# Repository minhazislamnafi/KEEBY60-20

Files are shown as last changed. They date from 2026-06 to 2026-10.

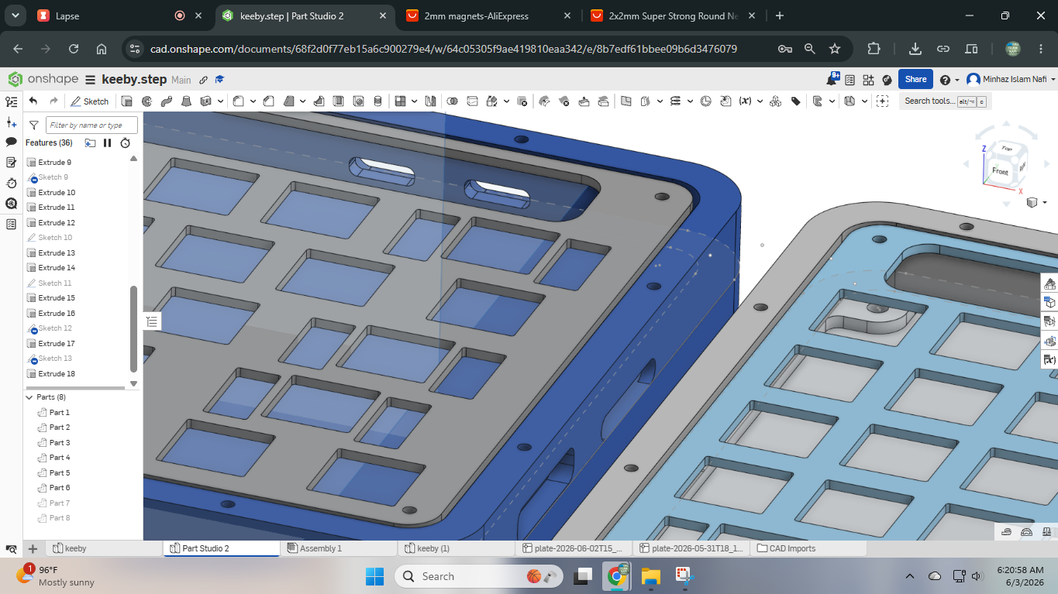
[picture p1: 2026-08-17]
DOCS/Screenshot 2026-06-03 062100.png

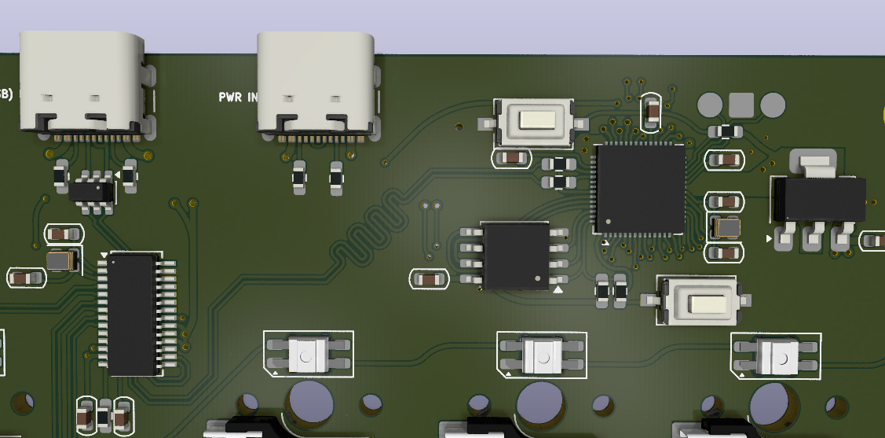
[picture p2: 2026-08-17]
DOCS/Screenshot 2026-06-07 144513.png

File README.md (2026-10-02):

# KEEBY60+20

A moduler 60% mechanical hot-swapble keyboard. With 20% numpad attachment, it will form a proper 80% keyboard.






GITHUB REPO

# Specification

## KEEBY60
* Firmware: QMK
* Layout: Default 60% (main Keyboard)
* Socket: Hot-swapable Kailh Socket
* Switches: Cherry MX blue
* ARGB led: SK6812 mini-E
* MCU: Raspberry Pi RP2040 QFN-56
* USB hub IC: Fe1.1s SSOP-28
* USB IN: 2 type-C (One for USB+Power & another for only power)
* USB OUT: 1 6p magnetic connector & 2 type-c usb 2.0
        
     (2 USB 2.0 is only accessible when only 60% is used)
* Total keys: 63 ANSI layout
* Knob: EC11E rotary encoder (with push switch)
* Diaplay: SSD1306 0.91" I2C Oled 
* PCB: 2-layer (all components bottom mounted)
* Dimensions: pcb - 291* 116 mm (L * W)                                                                        
              case - 304* 130*45 mm  (L * W * H)

## KEEBY20
* firmware: QMK
* Layout: ISO 20% (numpad)
* Socket: Hot-swapable Kailh Socket
* Switches: Cherry MX blue
* ARGB led: SK6812 mini-E
* MCU: Raspberry Pi RP2040 QFN-56
* USB IN: 6p magnetic connector & 1 type-C

     (Both the 6p conn and type-C connector's data pin are connected)
* Total keys: 17 ANSI Numpad
* Knob: EC11E rotary encoder (with push switch)
* Diaplay: SSD1306 0.91" I2C Oled 
* PCB: 2-layer (all components bottom mounted)
* Dimensions: pcb - 81* 116 mm (L * W)                                                                         
              case - 95* 130*45 mm (L * W * H)

# Ask Why KEEBY60+20?

It's a freaking 80% moduler usb2.0 hub, mechanical hot-swappable programmable ARGB LED DIY 3D printed Keyboard with dual knob dual OLED display. wants to know more? It can be used as a single 60% ANSI with 2 USB 2.0 HUB or, a single 17-key numpad macropad or or or as said, a 6-pin magnetic-connected ISO 80% Keyboard. 

TL;DR - The KEEBY60+20 is an all-around very versatile keyboard that runs on open-source QMK firmware.

## Onshape Full assembly [Link](https://cad.onshape.com/documents/68f2d0f77eb15a6c900279e4/w/64c05305f9ae419810eaa342/e/0ee3c387e4a094a987680ffc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)

## CAD Render
CAD render

## Schematics
Keeby60v2_page-0001

Keeby60v2_page-0003

## PCB Render
My PC can't handle KiCad 10.0 now. so no render ;(
But I have some screenshots.









## FOLLOW THESE STEPS FOR BUILDING ##

**1. Spend some money $$ to buy the parts mentioned in [BOM](https://github.com/minhazislamnafi/KEEBY60-20/tree/main/PCB/production).**(2 separate BOM)

**2. Order the PCB for KEEBY60 and KEEBY20 using this [GERBER file](https://github.com/minhazislamnafi/KEEBY60-20/blob/main/PCB/production/keeby60/KEEBY_60_v1.1.zip) and [GERBER file](https://github.com/minhazislamnafi/KEEBY60-20/blob/main/PCB/production/keeby20/KEEBY_20_v1.1.zip).**

**3. Solder the SMD components of the PCB by hand ;) Or just order the PCBs with PCBA services, btw it will cost a lot.**

**4. Check with a multimeter: Is the MCU getting 3.3v or not? If not, diagnose by yourself :)**

**5. Place all the key switches.**

**6. Flash QMK firmware using USB connection ( I will add every step in details, once I have built IRL:)**

**7. 3D print the [Case](https://github.com/minhazislamnafi/KEEBY60-20/tree/main/CAD/CASE%203D%20file) .**

**8. Assemble your KEEBY60 and 20.**

**5. Test and enjoy more RGB= more FPS keyboard ( I will add every step in details, once I have built IRL:).**

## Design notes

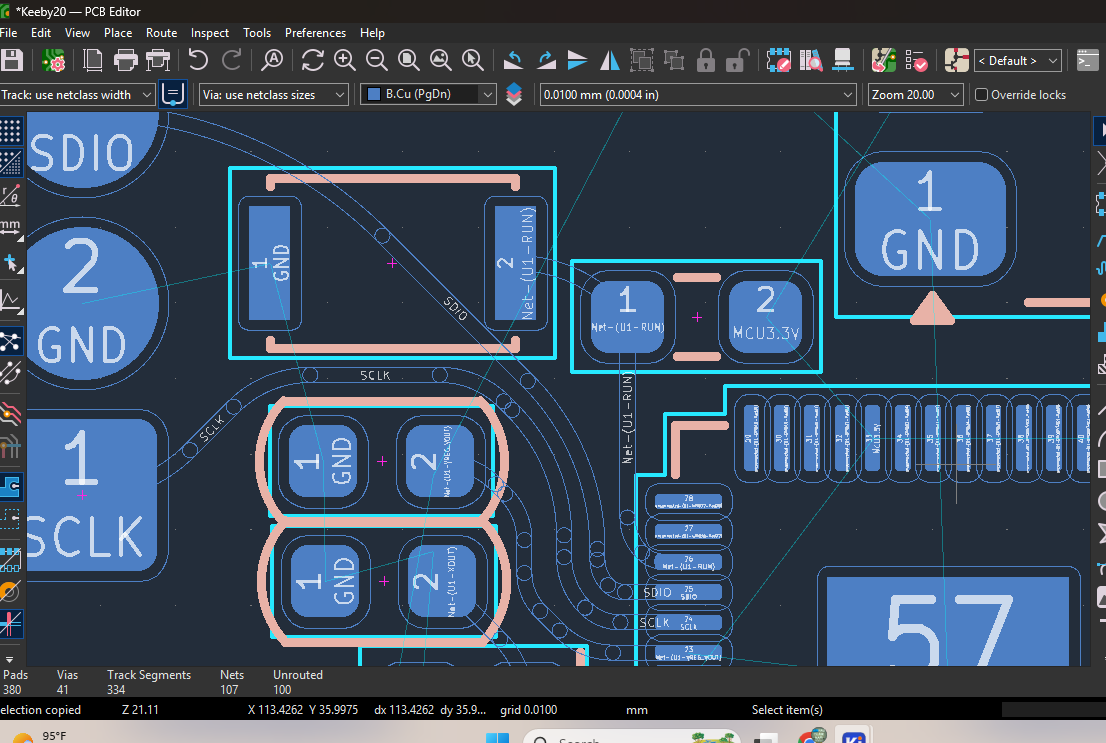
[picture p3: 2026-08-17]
DOCS/Screenshot 2026-05-31 063714.png

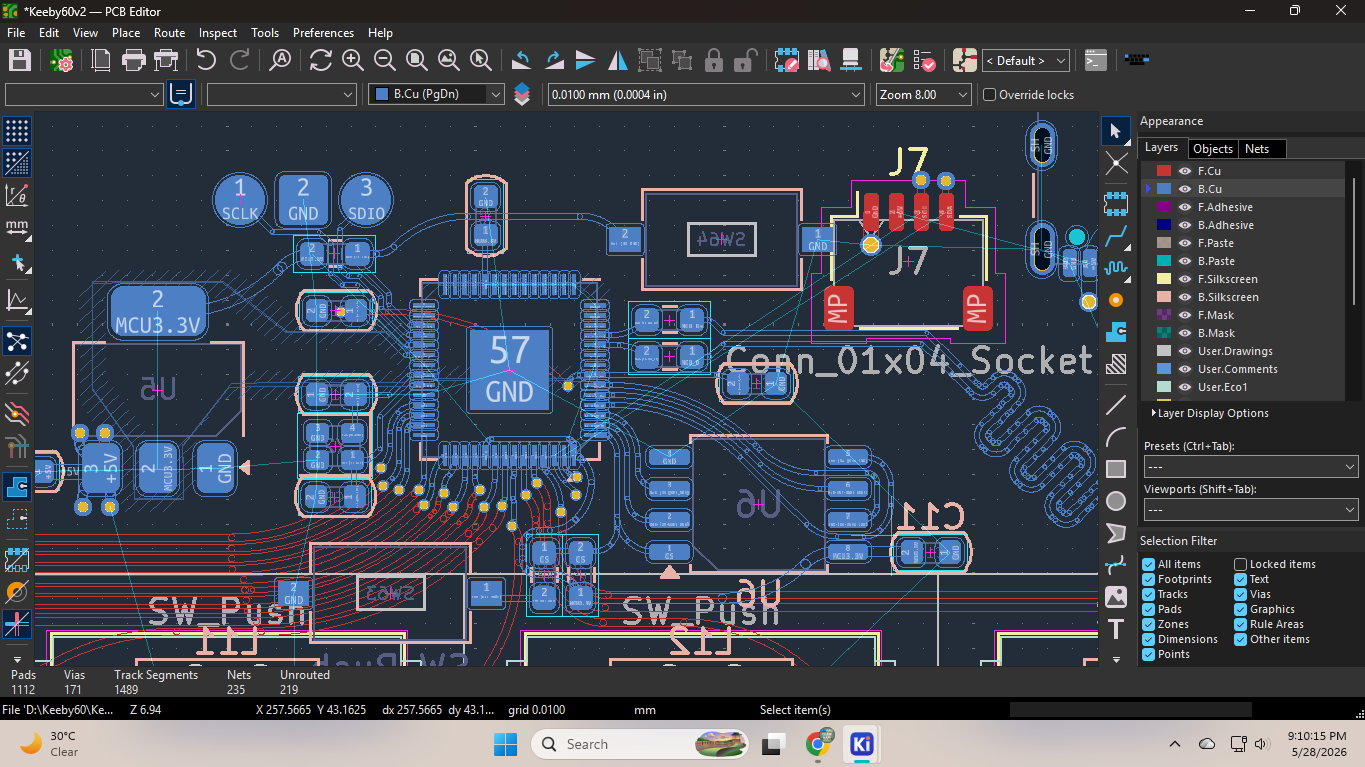
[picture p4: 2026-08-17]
DOCS/Screenshot 2026-05-28 211016.png

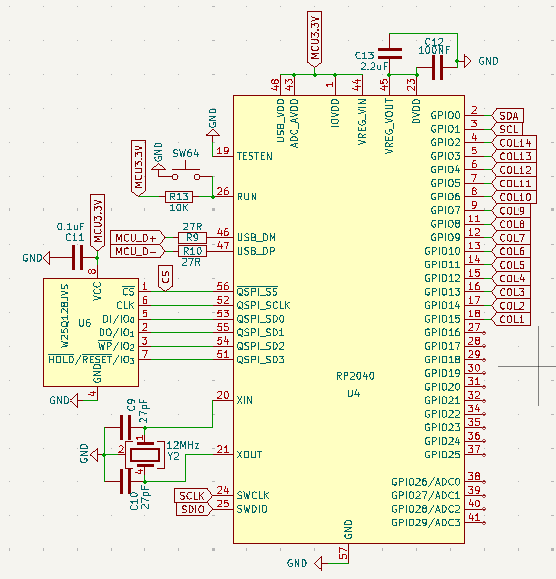
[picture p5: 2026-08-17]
DOCS/Screenshot 2026-05-28 212009.png

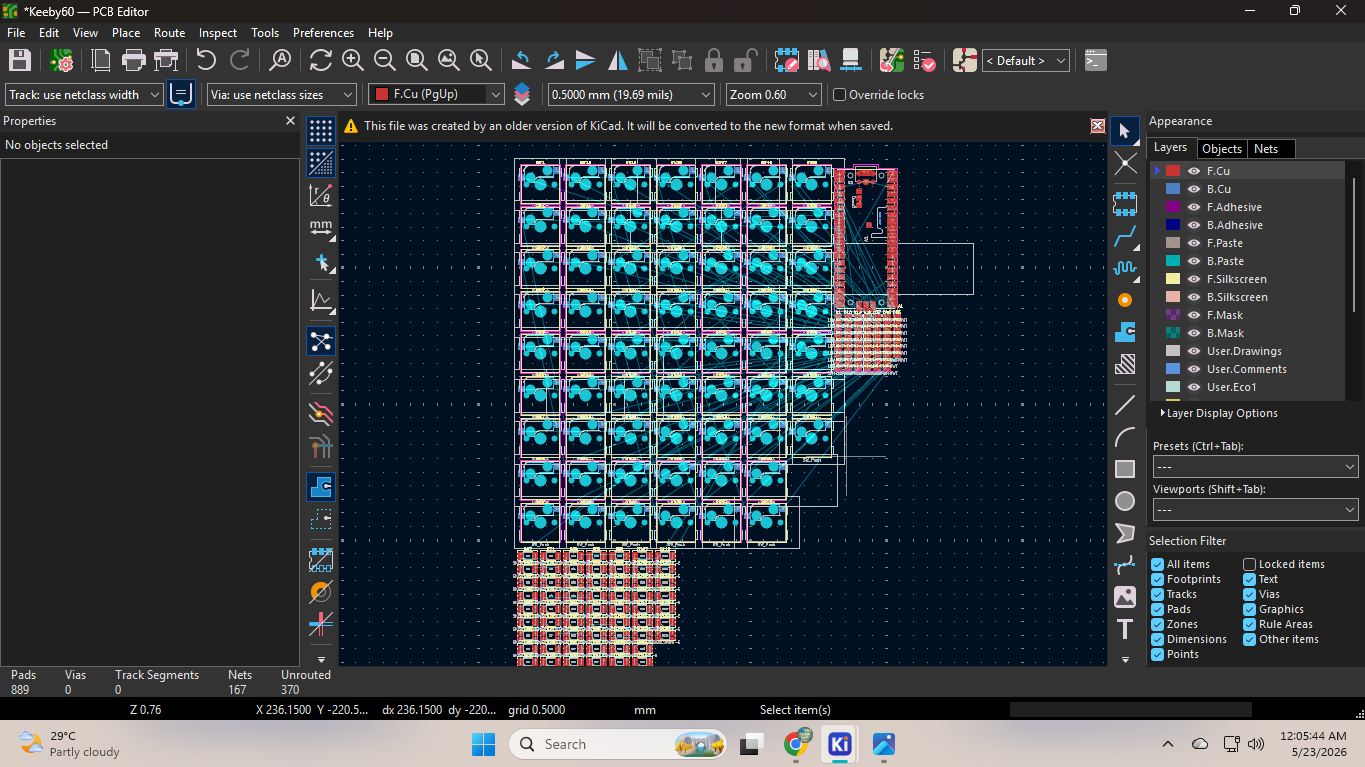
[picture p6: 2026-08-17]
DOCS/Screenshot 2026-05-23 000546 - Copy.png

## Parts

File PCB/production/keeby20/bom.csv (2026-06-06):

Designator | Footprint | Quantity | Value | LCSC Part #
C1 | 0603 | 1 | 2.2uF
C2 | 0603 | 1 | 100NF
C3 | 0603 | 1 | 0.1uF
C4, C5 | 0603 | 2 | 27pF
C6, C7 | 0603 | 2 | 10uF
D1, D10, D11, D12, D13, D14, D15, D16, D17, D2, D3, D4, D5, D6, D7, D8, D9 | D_SOD-523 | 17 | 1N4148WT
E1 | RotaryEncoder_Alps_EC11E-Switch_Vertical_H20mm_MountingHoles | 1 | RotaryEncoder_Switch_MP
J1 | USB_C_Receptacle_GCT_USB4105-xx-A_16P_TopMnt_Horizontal | 1 | USB_C_Receptacle_USB2.0_16P
J2 | JST_SH_SM04B-SRSS-TB_1x04-1MP_P1.00mm_Horizontal | 1 | Conn_01x05_Socket
J3 | TerminalBlock_Xinya_XY308-2.54-3P_1x03_P2.54mm_Horizontal | 1 | DEBUG PIN
J4 | PinHeader_1x06_P2.54mm_Vertical | 1 | Conn_01x06_Pin
L1, L10, L11, L12, L13, L14, L15, L16, L17, L2, L3, L4, L5, L6, L7, L8, L9 | LED_SK6812MINI-E_3.2x2.8mm_P1.5mm_ReverseMount | 17 | SK6812MINI-E
P1, P2 | SW_SPST_CK_KXT3 | 2 | SW_Push
R1, R2 | 0603 | 2 | 5.1K
R3, R7 | 0603 | 2 | 10K
R4, R5 | 0603 | 2 | 27R
R6 | 0603 | 1 | 1K
SW1, SW10, SW11, SW12, SW13, SW14, SW17, SW2, SW3, SW4, SW5, SW6, SW7, SW9 | SW_Hotswap_Kailh_MX_1.00u | 14 | SW_Push
SW15, SW8 | SW_Hotswap_Kailh_MX_2.00u_90deg | 2 | SW_Push
SW16 | SW_Hotswap_Kailh_MX_2.00u | 1 | SW_Push
U1 | QFN-56-1EP_7x7mm_P0.4mm_EP3.2x3.2mm | 1 | RP2040
U2 | SOIC-8_5.3x5.3mm_P1.27mm | 1 | W25Q128JVS
U3 | SOT-223-3_TabPin2 | 1 | AMS1117-3.3
Y1 | Crystal_SMD_2016-4Pin_2.0x1.6mm | 1 | 12MHz

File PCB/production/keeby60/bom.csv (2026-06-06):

Designator | Footprint | Quantity | Value | LCSC Part #
C10, C9 | 0603 | 2 | 27pF
C11 | 0603 | 1 | 0.1uF
C12 | 0603 | 1 | 100NF
C13 | 0603 | 1 | 2.2uF
C14, C15, C7, C8 | 0603 | 4 | 10uF
C16, C17 | 0603 | 2 | 22pF
D1, D10, D11, D12, D13, D14, D15, D16, D17, D18, D19, D2, D20, D21, D22, D23, D24, D25, D26, D27, D28, D29, D3, D30, D31, D32, D33, D34, D35, D36, D37, D38, D39, D4, D40, D41, D42, D43, D44, D45, D46, D47, D48, D49, D5, D50, D51, D52, D53, D54, D55, D56, D57, D58, D59, D6, D60, D61, D7, D8, D9 | D_SOD-523 | 61 | 1N4148WT
J1, J2, J3, J4 | USB_C_Receptacle_GCT_USB4105-xx-A_16P_TopMnt_Horizontal | 4 | USB_C_Receptacle_USB2.0_16P
J5 | TerminalBlock_Xinya_XY308-2.54-6P_1x06_P2.54mm_Horizontal | 1 | 6P magnetic connecter
J6 | TerminalBlock_Xinya_XY308-2.54-3P_1x03_P2.54mm_Horizontal | 1 | DEBUG PIN
J7 | JST_SH_SM04B-SRSS-TB_1x04-1MP_P1.00mm_Horizontal | 1 | Conn_01x05_Pin
L1, L10, L11, L12, L13, L14, L15, L16, L17, L18, L19, L2, L20, L21, L22, L23, L24, L25, L26, L27, L28, L29, L3, L30, L31, L32, L33, L34, L35, L36, L37, L38, L39, L4, L40, L41, L42, L43, L44, L45, L46, L47, L48, L49, L5, L50, L51, L52, L53, L54, L55, L56, L57, L58, L59, L6, L60, L61, L7, L8, L9 | LED_SK6812MINI-E_3.2x2.8mm_P1.5mm_ReverseMount | 61 | SK6812MINI-E
R1, R2, R3, R4, R5, R6, R7, R8 | 0603 | 8 | 5.1K
R10, R9 | 0603 | 2 | 27R
R11 | 0603 | 1 | 1K
R12, R13 | 0603 | 2 | 10K
R14 | 0603 | 1 | 12K
SW1, SW10, SW11, SW12, SW13, SW16, SW17, SW18, SW19, SW2, SW20, SW21, SW22, SW23, SW24, SW25, SW26, SW27, SW3, SW30, SW31, SW32, SW33, SW34, SW35, SW36, SW37, SW38, SW39, SW4, SW40, SW43, SW44, SW45, SW46, SW47, SW48, SW49, SW5, SW50, SW51, SW52, SW6, SW7, SW8, SW9 | SW_Hotswap_Kailh_MX_1.00u | 46 | SW_Push
SW14 | SW_Hotswap_Kailh_MX_2.00u | 1 | SW_Push
SW15, SW28 | SW_Hotswap_Kailh_MX_1.50u | 2 | SW_Push
SW29 | SW_Hotswap_Kailh_MX_1.75u | 1 | SW_Push
SW41, SW42 | SW_Hotswap_Kailh_MX_2.25u | 2 | SW_Push
SW53 | SW_Hotswap_Kailh_MX_2.75u | 1 | SW_Push
SW54, SW55, SW56, SW58, SW59, SW60, SW61 | SW_Hotswap_Kailh_MX_1.25u | 7 | SW_Push
SW57 | SW_Hotswap_Kailh_MX_6.25u | 1 | SW_Push
SW62 | RotaryEncoder_Alps_EC11E-Switch_Vertical_H20mm_MountingHoles | 1 | RotaryEncoder_Switch_MP
SW63, SW64 | SW_Tactile_SPST_NO_Straight_CK_PTS636Sx25SMTRLFS | 2 | SW_Push
U10, U8, U9 | SOT-23-6 | 3 | USBLC6-2SC6
U4 | QFN-56-1EP_7x7mm_P0.4mm_EP3.2x3.2mm | 1 | RP2040
U5 | SOT-223-3_TabPin2 | 1 | AMS1117-3.3
U6 | SOIC-8_5.3x5.3mm_P1.27mm | 1 | W25Q128JVS
U7 | SSOP-28_3.9x9.9mm_P0.635mm | 1 | FE1.1s
Y2, Y3 | Crystal_SMD_2016-4Pin_2.0x1.6mm | 2 | 12MHz

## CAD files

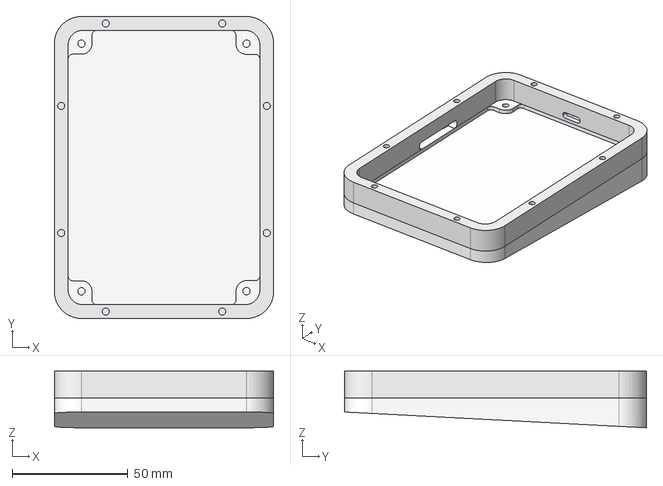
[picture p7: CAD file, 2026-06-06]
CAD/CASE 3D file/keeby20/KEEBY 20 main housing.step
95.0 x 130.7 x 24.5 mm

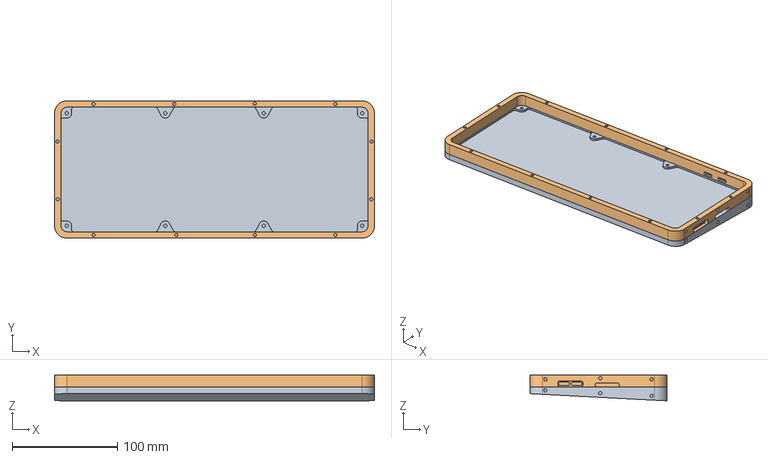
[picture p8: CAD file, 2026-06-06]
CAD/CASE 3D file/keeby60/KEEBY 60 main housing.step
304.5 x 130.7 x 24.5 mm

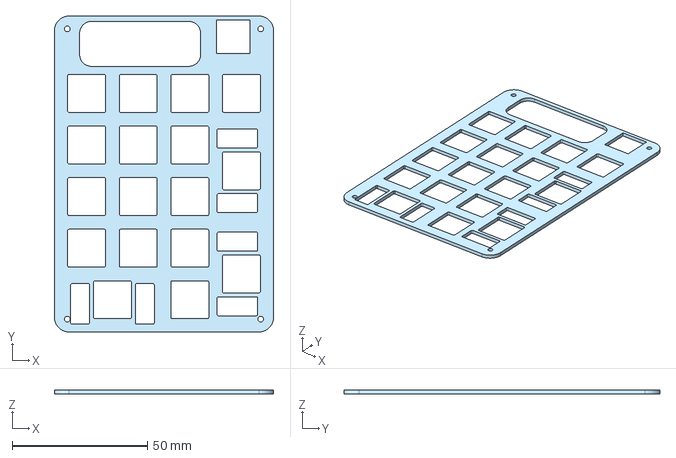
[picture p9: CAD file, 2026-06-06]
CAD/CASE 3D file/keeby20/KEEBY 20 mount Plate.step
81.0 x 116.7 x 1.50 mm

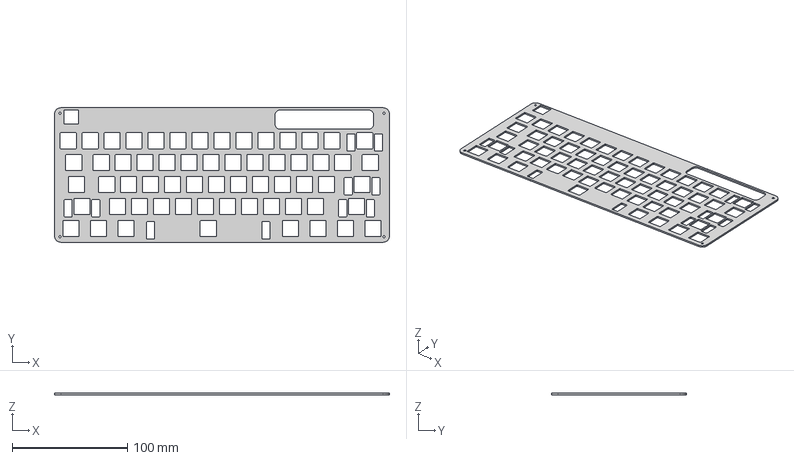
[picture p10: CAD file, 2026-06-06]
CAD/CASE 3D file/keeby60/KEEBY 60 mount Plate.step
290.5 x 116.7 x 1.50 mm

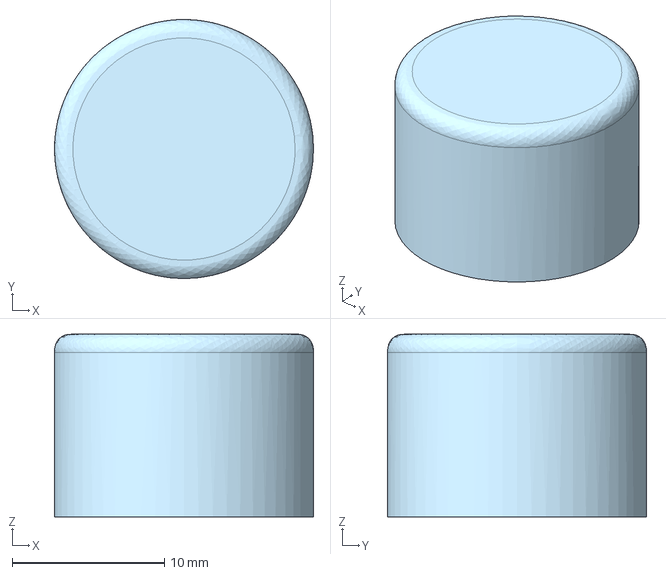
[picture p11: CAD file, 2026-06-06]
CAD/Encoder Knob/keeby rotary encoder knob.step
17.0 x 17.0 x 12.0 mm

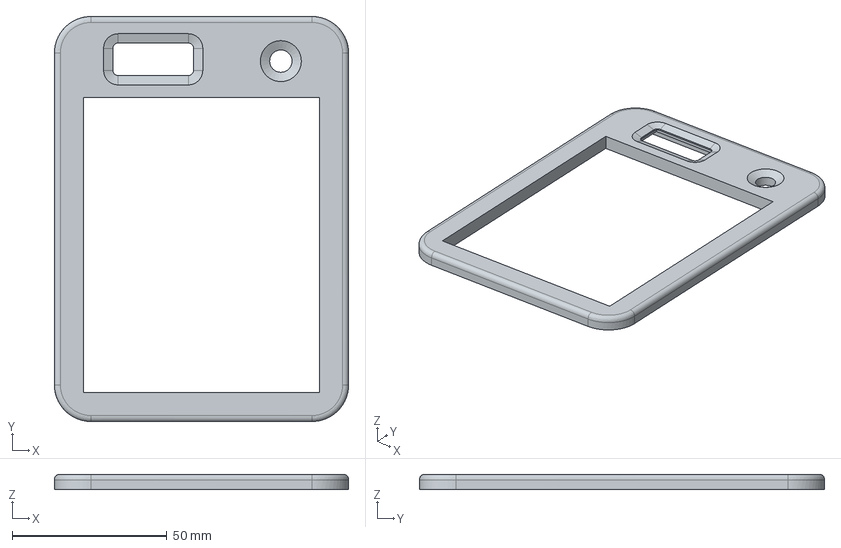
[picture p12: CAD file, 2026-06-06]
CAD/CASE 3D file/keeby20/KEEBY 20 top cover.step
95.0 x 130.7 x 5.00 mm

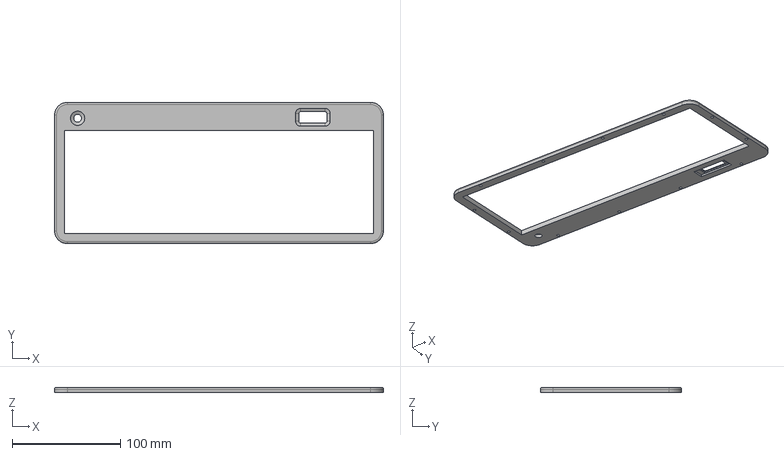
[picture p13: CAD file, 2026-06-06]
CAD/CASE 3D file/keeby60/KEEBY 60 top cover.step
304.5 x 130.7 x 5.00 mm

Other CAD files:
CAD/CASE 3D file/keeby20/KEEBY 20 main housing.stl
CAD/CASE 3D file/keeby20/KEEBY 20 mount Plate.stl
CAD/CASE 3D file/keeby20/KEEBY 20 top cover.stl
CAD/CASE 3D file/keeby60/KEEBY 60 main housing.stl
CAD/CASE 3D file/keeby60/KEEBY 60 mount Plate.stl
CAD/CASE 3D file/keeby60/KEEBY 60 top cover.stl
CAD/Encoder Knob/keeby rotary encoder knob.stl

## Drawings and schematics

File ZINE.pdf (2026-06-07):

# KEEBY

60+20

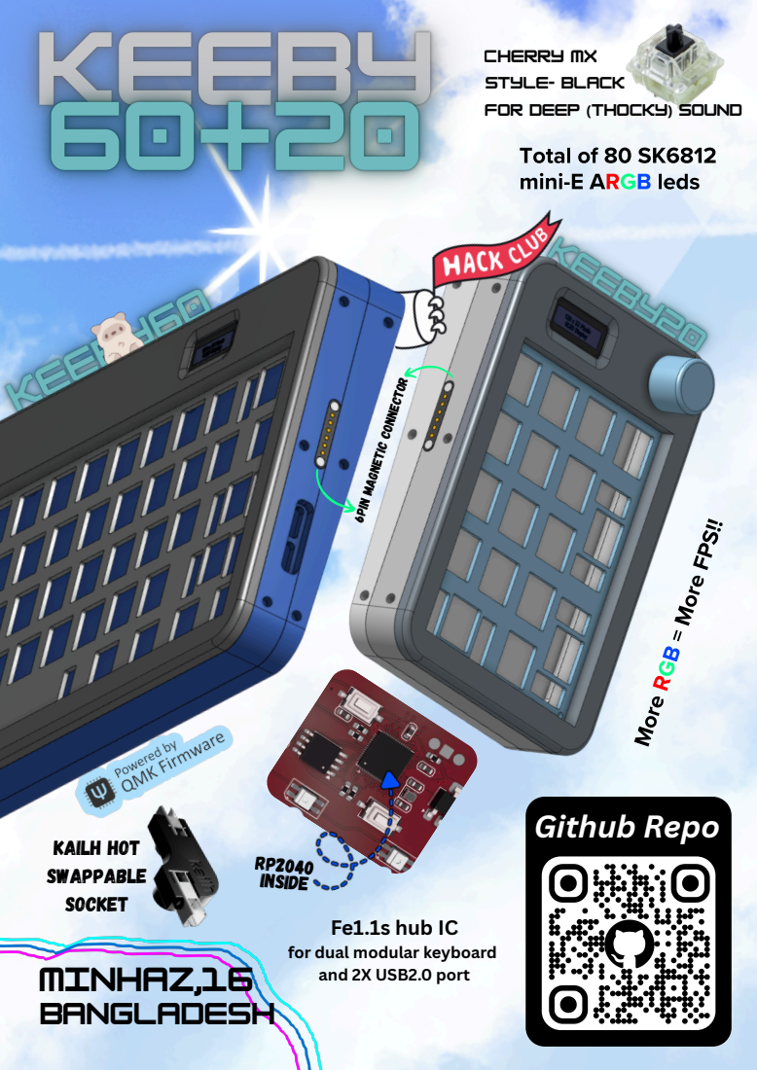
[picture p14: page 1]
KEEBY60; KEEBY20; 6PIN; MAGNETIC; CONNECTOR; Github Repo; MINHAZ,16 BANGLADESH; RP2040 inside; More; RGB; FPS!!; Kailh hot swappable socket

CHERRY MX
STYLE- BLACK
FOR DEEP (THOCKY) SOUND

Total of 80 SK6812
mini-E ARGB leds

Fe1.1s hub IC
for dual modular keyboard
and 2X USB2.0 port

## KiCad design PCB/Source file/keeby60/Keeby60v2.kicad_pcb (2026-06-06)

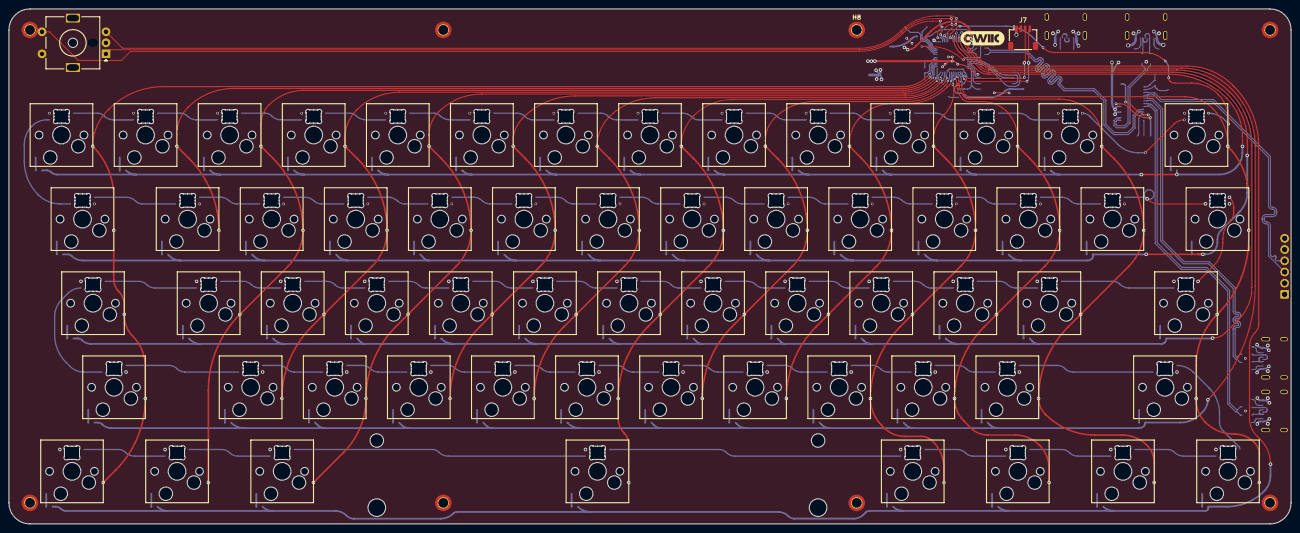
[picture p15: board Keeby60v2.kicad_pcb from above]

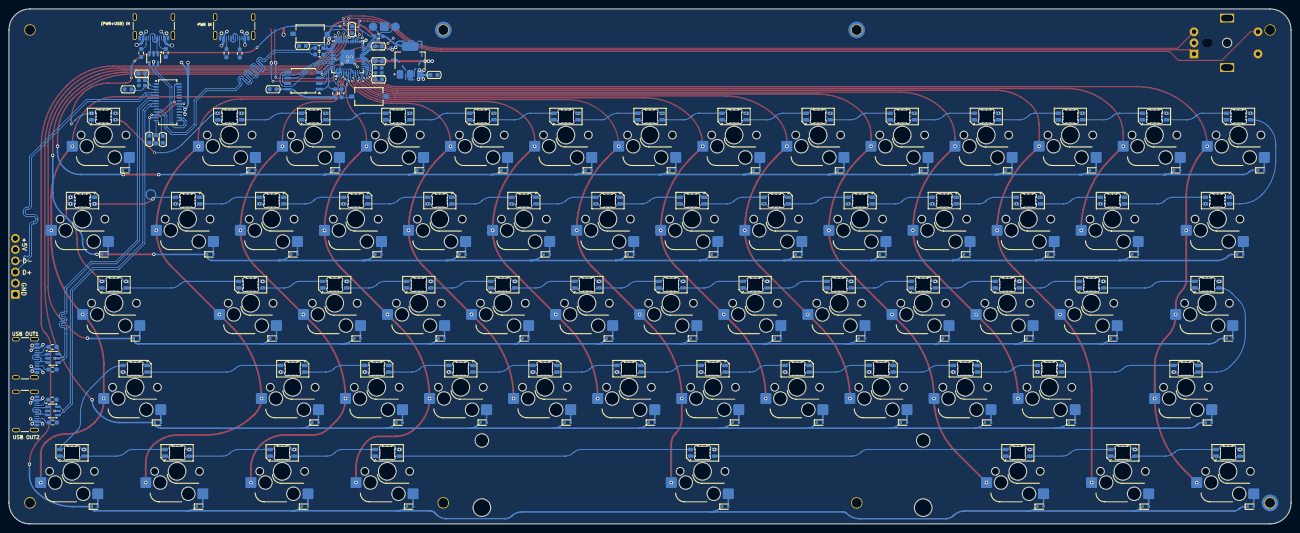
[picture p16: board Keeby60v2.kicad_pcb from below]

Board: 2 copper layers, 290.5 x 116.7 mm, 235 parts (163 on the bottom side), 195 nets.

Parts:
C7, C8, C14, C15: 10uF; C_0603_1608Metric
C9, C10: 27pF; C_0603_1608Metric
C11: 0.1uF; C_0603_1608Metric
C12: 100NF; C_0603_1608Metric
C13: 2.2uF; C_0603_1608Metric
C16, C17: 22pF; C_0603_1608Metric
D1, D2, D3, D4, D5, D6, D7, D8, D9, D10, D11, D12, D13, D14, D15, D16, D17, D18, D19, D20, D21, D22, D23, D24, D25, D26, D27, D28, D29, D30, D31, D32, D33, D34, D35, D36, D37, D38, D39, D40, D41, D42, D43, D44, D45, D46, D47, D48, D49, D50, D51, D52, D53, D54, D55, D56, D57, D58, D59, D60, D61: 1N4148WT; D_SOD-523
H1, H7, H8: MountingHole_Pad; MountingHole_2.2mm_M2_DIN965_Pad_TopBottom
H2, H3, H4, H5, H6: MountingHole_Pad; MountingHole_2.2mm_M2_DIN965_Pad_TopOnly
J1, J2, J3, J4: USB_C_Receptacle_USB2.0_16P; USB_C_Receptacle_GCT_USB4105-xx-A_16P_TopMnt_Horizontal
J5: 6P magnetic connecter; TerminalBlock_Xinya_XY308-2.54-6P_1x06_P2.54mm_Horizontal
J6: DEBUG PIN; TerminalBlock_Xinya_XY308-2.54-3P_1x03_P2.54mm_Horizontal
J7: Conn_01x05_Pin; JST_SH_SM04B-SRSS-TB_1x04-1MP_P1.00mm_Horizontal
L1, L2, L3, L4, L5, L6, L7, L8, L9, L10, L11, L12, L13, L14, L15, L16, L17, L18, L19, L20, L21, L22, L23, L24, L25, L26, L27, L28, L29, L30, L31, L32, L33, L34, L35, L36, L37, L38, L39, L40, L41, L42, L43, L44, L45, L46, L47, L48, L49, L50, L51, L52, L53, L54, L55, L56, L57, L58, L59, L60, L61: SK6812MINI-E; LED_SK6812MINI-E_3.2x2.8mm_P1.5mm_ReverseMount
R1, R2, R3, R4, R5, R6, R7, R8: 5.1K; R_0603_1608Metric_Pad0.98x0.95mm_HandSolder
R9, R10: 27R; R_0603_1608Metric_Pad0.98x0.95mm_HandSolder
R11: 1K; R_0603_1608Metric_Pad0.98x0.95mm_HandSolder
R12, R13: 10K; R_0603_1608Metric_Pad0.98x0.95mm_HandSolder
R14: 12K; R_0603_1608Metric_Pad0.98x0.95mm_HandSolder
SW1, SW2, SW3, SW4, SW5, SW6, SW7, SW8, SW9, SW10, SW11, SW12, SW13, SW16, SW17, SW18, SW19, SW20, SW21, SW22, SW23, SW24, SW25, SW26, SW27, SW30, SW31, SW32, SW33, SW34, SW35, SW36, SW37, SW38, SW39, SW40, SW43, SW44, SW45, SW46, SW47, SW48, SW49, SW50, SW51, SW52: SW_Push; SW_Hotswap_Kailh_MX_1.00u
SW14: SW_Push; SW_Hotswap_Kailh_MX_2.00u
SW15, SW28: SW_Push; SW_Hotswap_Kailh_MX_1.50u
SW29: SW_Push; SW_Hotswap_Kailh_MX_1.75u
SW41, SW42: SW_Push; SW_Hotswap_Kailh_MX_2.25u
SW53: SW_Push; SW_Hotswap_Kailh_MX_2.75u
SW54, SW55, SW56, SW58, SW59, SW60, SW61: SW_Push; SW_Hotswap_Kailh_MX_1.25u
SW57: SW_Push; SW_Hotswap_Kailh_MX_6.25u
SW62: RotaryEncoder_Switch_MP; RotaryEncoder_Alps_EC11E-Switch_Vertical_H20mm_MountingHoles
SW63, SW64: SW_Push; SW_Tactile_SPST_NO_Straight_CK_PTS636Sx25SMTRLFS
U4: RP2040; QFN-56-1EP_7x7mm_P0.4mm_EP3.2x3.2mm
U5: AMS1117-3.3; SOT-223-3_TabPin2
U6: W25Q128JVS; SOIC-8_5.3x5.3mm_P1.27mm
U7: FE1.1s; SSOP-28_3.9x9.9mm_P0.635mm
U8, U9, U10: USBLC6-2SC6; SOT-23-6
Y2, Y3: 12MHz; Crystal_SMD_2016-4Pin_2.0x1.6mm

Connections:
+5V: C7.1, J1.A4 (VBUS), J1.A9 (VBUS), J1.B4 (VBUS), J1.B9 (VBUS), J2.A4 (VBUS), J2.A9 (VBUS), J2.B4 (VBUS), J2.B9 (VBUS), J3.A4 (VBUS), J3.A9 (VBUS), J3.B4 (VBUS), J3.B9 (VBUS), J4.A4 (VBUS), J4.A9 (VBUS), J4.B4 (VBUS), J4.B9 (VBUS), J5.5, J5.6, J7.2, L1.3 (VDD), L2.3 (VDD), L3.3 (VDD), L4.3 (VDD), L5.3 (VDD), L6.3 (VDD), L7.3 (VDD), L8.3 (VDD), L9.3 (VDD), L10.3 (VDD), L11.3 (VDD), L12.3 (VDD), L13.3 (VDD), L14.3 (VDD), L15.3 (VDD), L16.3 (VDD), L17.3 (VDD), L18.3 (VDD), L19.3 (VDD), L20.3 (VDD), L21.3 (VDD), L22.3 (VDD), L23.3 (VDD), L24.3 (VDD), L25.3 (VDD), L26.3 (VDD), L27.3 (VDD), L28.3 (VDD), L29.3 (VDD), L30.3 (VDD), L31.3 (VDD), L32.3 (VDD), L33.3 (VDD), L34.3 (VDD), L35.3 (VDD), L36.3 (VDD), L37.3 (VDD), L38.3 (VDD), L39.3 (VDD), L40.3 (VDD), L41.3 (VDD), L42.3 (VDD), L43.3 (VDD), L44.3 (VDD), L45.3 (VDD), L46.3 (VDD), L47.3 (VDD), L48.3 (VDD), L49.3 (VDD), L50.3 (VDD), L51.3 (VDD), L52.3 (VDD), L53.3 (VDD), L54.3 (VDD), L55.3 (VDD), L56.3 (VDD), L57.3 (VDD), L58.3 (VDD), L59.3 (VDD), L60.3 (VDD), L61.3 (VDD), U5.3 (VI), U7.18 (VBUSM), U7.20 (VDD5), U8.5 (VBUS), U9.5 (VBUS), U10.5 (VBUS)
COL1: SW1.1, SW15.1, SW29.1, SW42.1, SW54.1, U4.18 (GPIO15)
COL2: SW2.1, SW16.1, U4.17 (GPIO14)
COL3: SW3.1, SW17.1, SW30.1, SW55.1, U4.16 (GPIO13)
COL4: SW4.1, SW18.1, SW31.1, SW43.1, U4.15 (GPIO12)
COL5: SW5.1, SW19.1, SW32.1, SW44.1, SW56.1, U4.14 (GPIO11)
COL6: SW6.1, SW20.1, SW33.1, SW45.1, U4.13 (GPIO10)
COL7: SW7.1, SW21.1, SW34.1, SW46.1, U4.12 (GPIO9)
COL8: SW8.1, SW22.1, SW35.1, SW47.1, SW57.1, U4.11 (GPIO8)
COL9: SW9.1, SW23.1, SW36.1, SW48.1, U4.9 (GPIO7)
COL10: SW10.1, SW24.1, SW37.1, SW49.1, U4.8 (GPIO6)
COL11: SW11.1, SW25.1, SW38.1, SW50.1, SW58.1, U4.7 (GPIO5)
COL12: SW12.1, SW26.1, SW39.1, SW51.1, SW59.1, U4.6 (GPIO4)
COL13: SW13.1, SW27.1, SW40.1, SW52.1, SW60.1, U4.5 (GPIO3)
COL14: SW14.1, SW28.1, SW41.1, SW53.1, SW61.1, U4.4 (GPIO2)
CS: R11.1, R12.2, U4.56 (~QSPI_SS), U6.1 (~CS)
DIN: L14.2 (DIN), U4.36 (GPIO24)
GND: C7.2, C8.2, C9.2, C10.1, C11.1, C12.1, C13.2, C14.1, C15.1, C16.1, C17.2, H1.1 (1_1), H2.1 (1_1), H3.1 (1_1), H5.1 (1_1), H6.1 (1_1), H7.1 (1_1), H8.1 (1_1), J1.A1 (GND), J1.A12 (GND), J1.B1 (GND), J1.B12 (GND), J1.SH (SHIELD), J2.A1 (GND), J2.A12 (GND), J2.B1 (GND), J2.B12 (GND), J2.SH (SHIELD), J3.A1 (GND), J3.A12 (GND), J3.B1 (GND), J3.B12 (GND), J3.SH (SHIELD), J4.A1 (GND), J4.A12 (GND), J4.B1 (GND), J4.B12 (GND), J4.SH (SHIELD), J5.1, J5.2, J6.2, J7.1, L1.1 (VSS), L2.1 (VSS), L3.1 (VSS), L4.1 (VSS), L5.1 (VSS), L6.1 (VSS), L7.1 (VSS), L8.1 (VSS), L9.1 (VSS), L10.1 (VSS), L11.1 (VSS), L12.1 (VSS), L13.1 (VSS), L14.1 (VSS), L15.1 (VSS), L16.1 (VSS), L17.1 (VSS), L18.1 (VSS), L19.1 (VSS), L20.1 (VSS), L21.1 (VSS), L22.1 (VSS), L23.1 (VSS), L24.1 (VSS), L25.1 (VSS), L26.1 (VSS), L27.1 (VSS), L28.1 (VSS), L29.1 (VSS), L30.1 (VSS), L31.1 (VSS), L32.1 (VSS), L33.1 (VSS), L34.1 (VSS), L35.1 (VSS), L36.1 (VSS), L37.1 (VSS), L38.1 (VSS), L39.1 (VSS), L40.1 (VSS), L41.1 (VSS), L42.1 (VSS), L43.1 (VSS), L44.1 (VSS), L45.1 (VSS), L46.1 (VSS), L47.1 (VSS), L48.1 (VSS), L49.1 (VSS), L50.1 (VSS), L51.1 (VSS), L52.1 (VSS), L53.1 (VSS), L54.1 (VSS), L55.1 (VSS), L56.1 (VSS), L57.1 (VSS), L58.1 (VSS), L59.1 (VSS), L60.1 (VSS), L61.1 (VSS), R1.2, R2.2, R3.2, R4.2, R5.2, R6.2, R7.2, R8.2, R14.1, SW62.C, SW62.MP, SW62.S2, SW63.2, SW64.1, U4.19 (TESTEN), U4.57 (GND), U5.1 (GND), U6.4 (GND), U7.1 (VSS), U7.27 (TESTJ/EESDA), U8.2 (GND), U9.2 (GND), U10.2 (GND), Y2.2 (G), Y2.3 (G), Y3.2 (G), Y3.3 (G)
MAG_D+: J5.3, U7.5 (DP4)
MAG_D-: J5.4, U7.4 (DM4)
MCU3.3V: C8.1, C11.2, R12.1, R13.2, U4.1 (IOVDD), U4.10 (IOVDD), U4.22 (IOVDD), U4.33 (IOVDD), U4.42 (IOVDD), U4.43 (ADC_AVDD), U4.44 (VREG_VIN), U4.48 (USB_VDD), U4.49 (IOVDD), U5.2 (VO), U6.8 (VCC)
MCU_D+: R9.1, U7.10 (DM1)
MCU_D-: R10.1, U7.11 (DP1)
unnamed: D1.2 (A), SW1.2
unnamed: D2.2 (A), SW2.2
unnamed: D3.2 (A), SW3.2
unnamed: D4.2 (A), SW4.2
unnamed: D5.2 (A), SW5.2
unnamed: D6.2 (A), SW6.2
unnamed: D7.2 (A), SW7.2
unnamed: D8.2 (A), SW8.2
unnamed: D9.2 (A), SW9.2
unnamed: D10.2 (A), SW10.2
unnamed: D11.2 (A), SW11.2
unnamed: D12.2 (A), SW12.2
unnamed: D13.2 (A), SW13.2
unnamed: D14.2 (A), SW14.2
unnamed: D15.2 (A), SW15.2
unnamed: D16.2 (A), SW16.2
unnamed: D17.2 (A), SW17.2
unnamed: D18.2 (A), SW18.2
unnamed: D19.2 (A), SW19.2
unnamed: D20.2 (A), SW20.2
unnamed: D21.2 (A), SW21.2
unnamed: D22.2 (A), SW22.2
unnamed: D23.2 (A), SW23.2
unnamed: D24.2 (A), SW24.2
unnamed: D25.2 (A), SW25.2
unnamed: D26.2 (A), SW26.2
unnamed: D27.2 (A), SW27.2
unnamed: D28.2 (A), SW28.2
unnamed: D29.2 (A), SW29.2
unnamed: D30.2 (A), SW30.2
unnamed: D31.2 (A), SW31.2
unnamed: D32.2 (A), SW32.2
unnamed: D33.2 (A), SW33.2
unnamed: D34.2 (A), SW34.2
unnamed: D35.2 (A), SW35.2
unnamed: D36.2 (A), SW36.2
unnamed: D37.2 (A), SW37.2
unnamed: D38.2 (A), SW38.2
unnamed: D39.2 (A), SW39.2
unnamed: D40.2 (A), SW40.2
unnamed: D41.2 (A), SW41.2
unnamed: D42.2 (A), SW42.2
unnamed: D43.2 (A), SW43.2
unnamed: D44.2 (A), SW44.2
unnamed: D45.2 (A), SW45.2
unnamed: D46.2 (A), SW46.2
unnamed: D47.2 (A), SW47.2
unnamed: D48.2 (A), SW48.2
unnamed: D49.2 (A), SW49.2
unnamed: D50.2 (A), SW50.2
unnamed: D51.2 (A), SW51.2
unnamed: D52.2 (A), SW52.2
unnamed: D53.2 (A), SW53.2
unnamed: D54.2 (A), SW54.2
unnamed: D55.2 (A), SW55.2
unnamed: D56.2 (A), SW56.2
unnamed: D57.2 (A), SW57.2
unnamed: D58.2 (A), SW58.2
unnamed: D59.2 (A), SW59.2
unnamed: D60.2 (A), SW60.2
unnamed: D61.2 (A), SW61.2
unnamed: J1.A5 (CC1), R5.1
unnamed: J1.B5 (CC2), R6.1
unnamed: J1.A6 (D+), J1.B6 (D+), U8.3 (I/O2)
unnamed: J1.A7 (D-), J1.B7 (D-), U8.1 (I/O1)
unnamed: J2.A5 (CC1), R1.1
unnamed: J2.B5 (CC2), R2.1
unnamed: J2.A6 (D+), J2.B6 (D+), U9.3 (I/O2)
unnamed: J2.A7 (D-), J2.B7 (D-), U9.1 (I/O1)
unnamed: J3.A5 (CC1), R3.1
unnamed: J3.B5 (CC2), R4.1
unnamed: J3.A6 (D+), J3.B6 (D+), U10.3 (I/O2)
unnamed: J3.A7 (D-), J3.B7 (D-), U10.1 (I/O1)
unnamed: J4.A5 (CC1), R7.1
unnamed: J4.B5 (CC2), R8.1
unnamed: J4.A6 (D+), J4.B6 (D+)
unnamed: J4.A7 (D-), J4.B7 (D-)
unnamed: L1.2 (DIN), L2.4 (DOUT)
unnamed: L1.4 (DOUT), L15.2 (DIN)
unnamed: L2.2 (DIN), L3.4 (DOUT)
unnamed: L3.2 (DIN), L4.4 (DOUT)
unnamed: L4.2 (DIN), L5.4 (DOUT)
unnamed: L5.2 (DIN), L6.4 (DOUT)
unnamed: L6.2 (DIN), L7.4 (DOUT)
unnamed: L7.2 (DIN), L8.4 (DOUT)
unnamed: L8.2 (DIN), L9.4 (DOUT)
unnamed: L10.2 (DIN), L11.4 (DOUT)
unnamed: L9.2 (DIN), L10.4 (DOUT)
unnamed: L11.2 (DIN), L12.4 (DOUT)
unnamed: L12.2 (DIN), L13.4 (DOUT)
unnamed: L13.2 (DIN), L14.4 (DOUT)
unnamed: L15.4 (DOUT), L16.2 (DIN)
unnamed: L16.4 (DOUT), L17.2 (DIN)
unnamed: L17.4 (DOUT), L18.2 (DIN)
unnamed: L18.4 (DOUT), L19.2 (DIN)
unnamed: L19.4 (DOUT), L20.2 (DIN)
unnamed: L20.4 (DOUT), L21.2 (DIN)
unnamed: L21.4 (DOUT), L22.2 (DIN)
unnamed: L22.4 (DOUT), L23.2 (DIN)
unnamed: L23.4 (DOUT), L24.2 (DIN)
unnamed: L24.4 (DOUT), L25.2 (DIN)
unnamed: L25.4 (DOUT), L26.2 (DIN)
unnamed: L26.4 (DOUT), L27.2 (DIN)
unnamed: L27.4 (DOUT), L28.2 (DIN)
unnamed: L28.4 (DOUT), L41.2 (DIN)
unnamed: L29.2 (DIN), L30.4 (DOUT)
unnamed: L29.4 (DOUT), L42.2 (DIN)
unnamed: L30.2 (DIN), L31.4 (DOUT)
unnamed: L31.2 (DIN), L32.4 (DOUT)
unnamed: L32.2 (DIN), L33.4 (DOUT)
unnamed: L33.2 (DIN), L34.4 (DOUT)
unnamed: L34.2 (DIN), L35.4 (DOUT)
unnamed: L35.2 (DIN), L36.4 (DOUT)
unnamed: L36.2 (DIN), L37.4 (DOUT)
unnamed: L37.2 (DIN), L38.4 (DOUT)
unnamed: L38.2 (DIN), L39.4 (DOUT)
unnamed: L39.2 (DIN), L40.4 (DOUT)
unnamed: L40.2 (DIN), L41.4 (DOUT)
unnamed: L42.4 (DOUT), L43.2 (DIN)
unnamed: L43.4 (DOUT), L44.2 (DIN)
unnamed: L44.4 (DOUT), L45.2 (DIN)
unnamed: L45.4 (DOUT), L46.2 (DIN)
unnamed: L46.4 (DOUT), L47.2 (DIN)
unnamed: L47.4 (DOUT), L48.2 (DIN)
unnamed: L48.4 (DOUT), L49.2 (DIN)
unnamed: L49.4 (DOUT), L50.2 (DIN)
unnamed: L50.4 (DOUT), L51.2 (DIN)
unnamed: L51.4 (DOUT), L52.2 (DIN)
unnamed: L52.4 (DOUT), L53.2 (DIN)
unnamed: L53.4 (DOUT), L61.2 (DIN)
unnamed: L54.2 (DIN), L55.4 (DOUT)
unnamed: L55.2 (DIN), L56.4 (DOUT)
unnamed: L56.2 (DIN), L57.4 (DOUT)
unnamed: L57.2 (DIN), L58.4 (DOUT)
unnamed: L58.2 (DIN), L59.4 (DOUT)
unnamed: L59.2 (DIN), L60.4 (DOUT)
unnamed: L60.2 (DIN), L61.4 (DOUT)
unnamed: R11.2, SW63.1
unnamed: U4.52 (QSPI_SCLK), U6.6 (CLK)
unnamed: U4.53 (QSPI_SD0), U6.5 (DI/IO_{0})
unnamed: U4.55 (QSPI_SD1), U6.2 (DO/IO_{1})
unnamed: U4.54 (QSPI_SD2), U6.3 (~WP/IO_{2})
unnamed: U4.51 (QSPI_SD3), U6.7 (~HOLD/~RESET/IO_{3})
unnamed: R13.1, SW64.2, U4.26 (RUN)
unnamed: R9.2, U4.46 (USB_DM)
unnamed: R10.2, U4.47 (USB_DP)
unnamed: C12.2, C13.1, U4.23 (DVDD), U4.45 (VREG_VOUT), U4.50 (DVDD)
unnamed: C9.1, U4.20 (XIN), Y2.1
unnamed: C10.2, U4.21 (XOUT), Y2.4
unnamed: R14.2, U7.14 (REXT)
unnamed: C15.2, U7.12 (VD18_O), U7.28 (VD18)
unnamed: C14.2, U7.13 (VD33), U7.21 (VD33_O)
unnamed: C17.1, U7.3 (XIN), Y3.4
unnamed: C16.2, U7.2 (XOUT), Y3.1
OUTA: SW62.A, U4.31 (GPIO20)
OUTB: SW62.B, U4.32 (GPIO21)
ROW1: D1.1 (K), D2.1 (K), D3.1 (K), D4.1 (K), D5.1 (K), D6.1 (K), D7.1 (K), D8.1 (K), D9.1 (K), D10.1 (K), D11.1 (K), D12.1 (K), D13.1 (K), D14.1 (K), U4.37 (GPIO25)
ROW2: D15.1 (K), D16.1 (K), D17.1 (K), D18.1 (K), D19.1 (K), D20.1 (K), D21.1 (K), D22.1 (K), D23.1 (K), D24.1 (K), D25.1 (K), D26.1 (K), D27.1 (K), D28.1 (K), U4.38 (GPIO26/ADC0)
ROW3: D29.1 (K), D30.1 (K), D31.1 (K), D32.1 (K), D33.1 (K), D34.1 (K), D35.1 (K), D36.1 (K), D37.1 (K), D38.1 (K), D39.1 (K), D40.1 (K), D41.1 (K), U4.39 (GPIO27/ADC1)
ROW4: D42.1 (K), D43.1 (K), D44.1 (K), D45.1 (K), D46.1 (K), D47.1 (K), D48.1 (K), D49.1 (K), D50.1 (K), D51.1 (K), D52.1 (K), D53.1 (K), U4.40 (GPIO28/ADC2)
ROW5: D54.1 (K), D55.1 (K), D56.1 (K), D57.1 (K), D58.1 (K), D59.1 (K), D60.1 (K), D61.1 (K), U4.41 (GPIO29/ADC3)
SCL: J7.4, U4.3 (GPIO1)
SCLK: J6.1, U4.24 (SWCLK)
SDA: J7.3, U4.2 (GPIO0)
SDIO: J6.3, U4.25 (SWDIO)
SW: H4.1 (1_1), SW62.S1, U4.30 (GPIO19)
USBD1D+: U7.9 (DP2), U9.4 (I/O2)
USBD1D-: U7.8 (DM2), U9.6 (I/O1)
USBD2D+: U7.7 (DP3), U10.4 (I/O2)
USBD2D-: U7.6 (DM3), U10.6 (I/O1)
USBUD+: U7.16 (DPU), U8.4 (I/O2)
USBUD-: U7.15 (DMU), U8.6 (I/O1)

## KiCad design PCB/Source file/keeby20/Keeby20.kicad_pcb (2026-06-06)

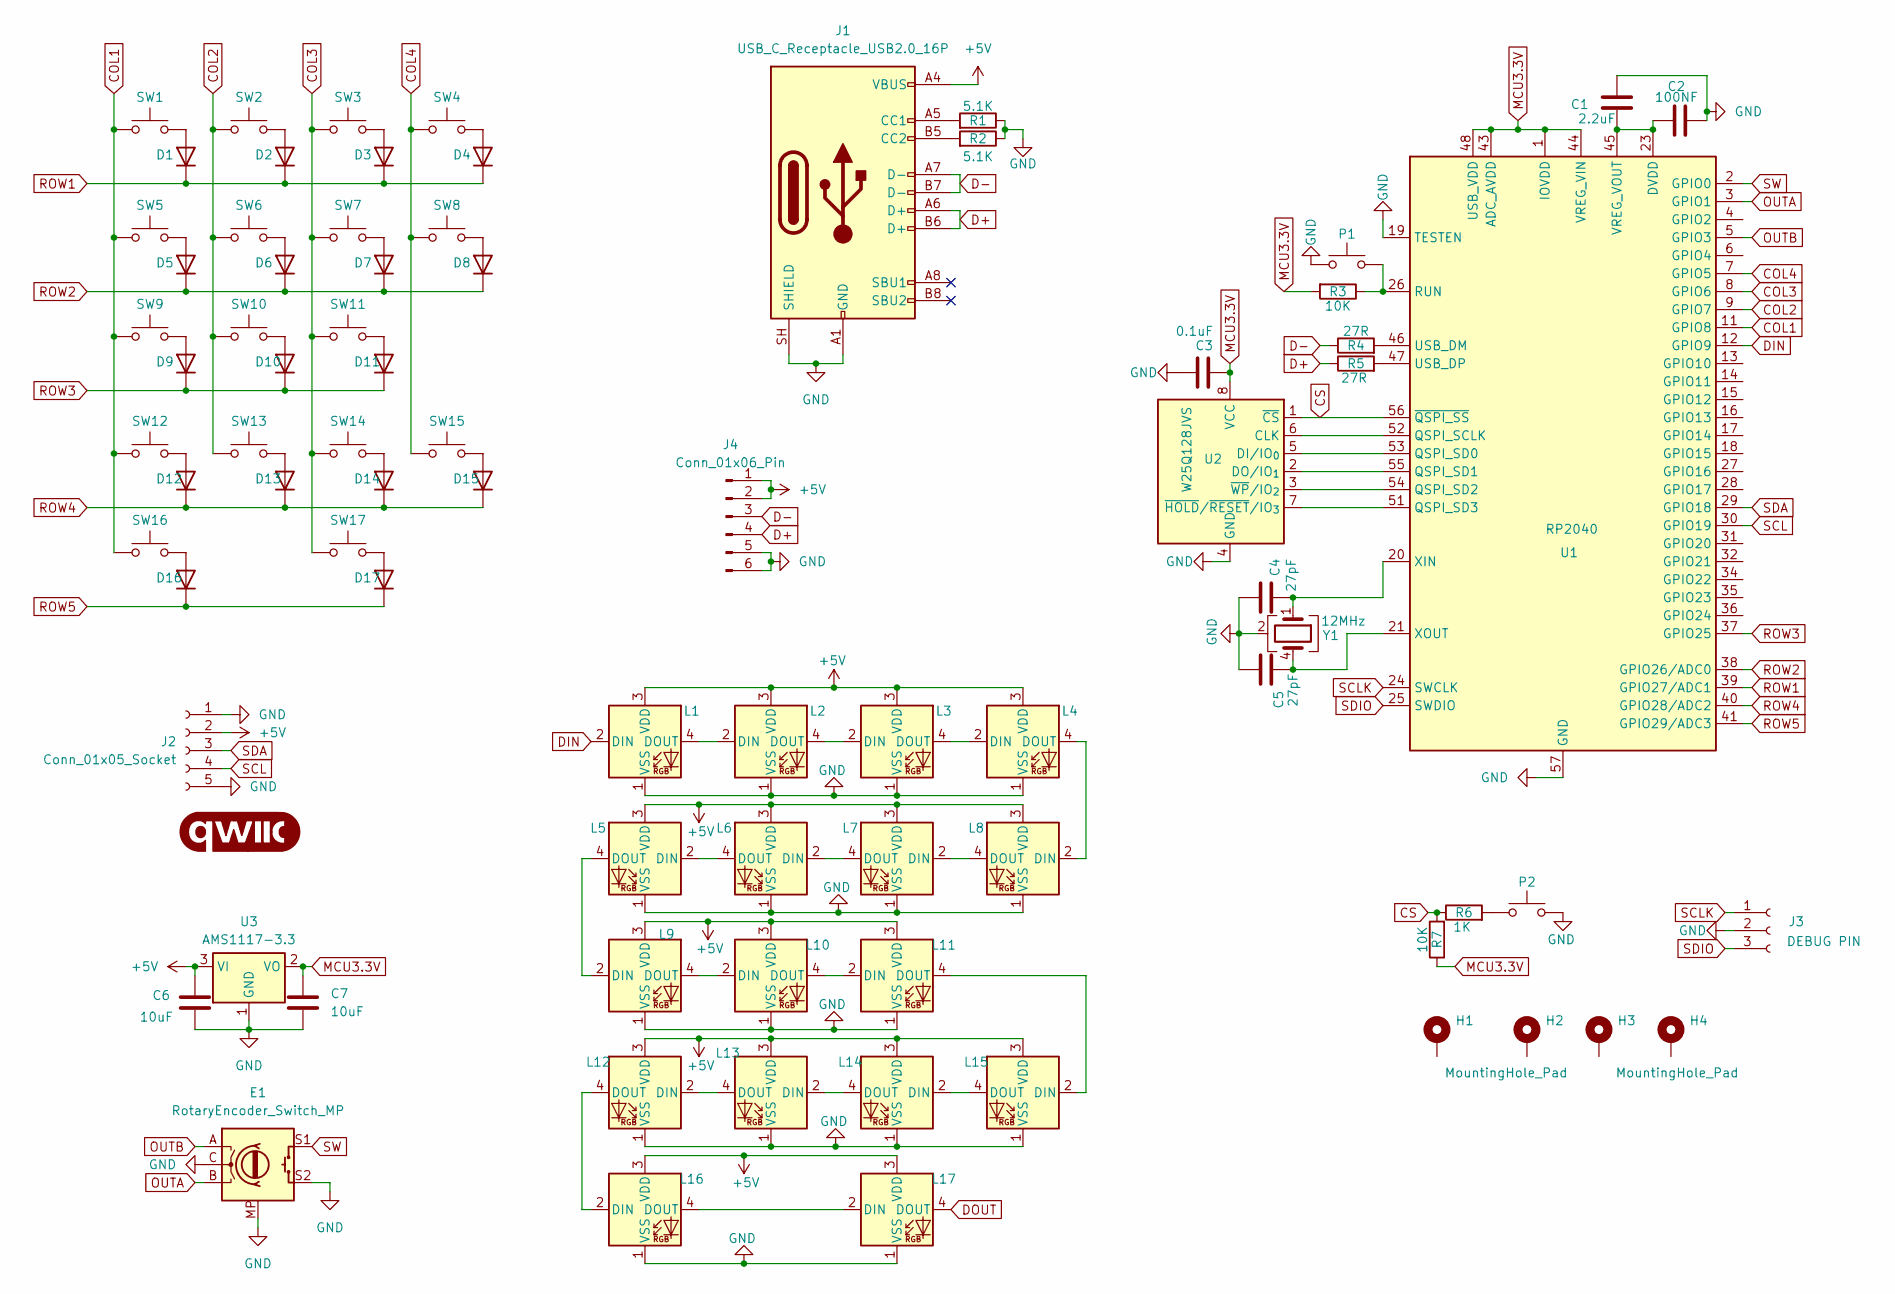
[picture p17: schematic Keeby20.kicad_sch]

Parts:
C1: 2.2uF; C_0603_1608Metric
C2: 100NF; C_0603_1608Metric
C3: 0.1uF; C_0603_1608Metric
C4, C5: 27pF; C_0603_1608Metric
C6, C7: 10uF; C_0603_1608Metric
D1, D2, D3, D4, D5, D6, D7, D8, D9, D10, D11, D12, D13, D14, D15, D16, D17: 1N4148WT; D_SOD-523
E1: RotaryEncoder_Switch_MP; RotaryEncoder_Alps_EC11E-Switch_Vertical_H20mm_MountingHoles
G1: qwiic_Logo
H1, H2, H3, H4: MountingHole_Pad; MountingHole_2.2mm_M2_Pad
J1: USB_C_Receptacle_USB2.0_16P; USB_C_Receptacle_GCT_USB4105-xx-A_16P_TopMnt_Horizontal
J2: Conn_01x05_Socket; JST_SH_SM04B-SRSS-TB_1x04-1MP_P1.00mm_Horizontal
J3: DEBUG PIN; TerminalBlock_Xinya_XY308-2.54-3P_1x03_P2.54mm_Horizontal
J4: Conn_01x06_Pin; PinHeader_1x06_P2.54mm_Vertical
L1, L2, L3, L4, L5, L6, L7, L8, L9, L10, L11, L12, L13, L14, L15, L16, L17: SK6812MINI-E; LED_SK6812MINI-E_3.2x2.8mm_P1.5mm_ReverseMount
P1, P2: SW_Push; SW_SPST_CK_KXT3
R1, R2: 5.1K; R_0603_1608Metric
R3, R7: 10K; R_0603_1608Metric_Pad0.98x0.95mm_HandSolder
R4, R5: 27R; R_0603_1608Metric_Pad0.98x0.95mm_HandSolder
R6: 1K; R_0603_1608Metric_Pad0.98x0.95mm_HandSolder
SW1, SW2, SW3, SW4, SW5, SW6, SW7, SW9, SW10, SW11, SW12, SW13, SW14, SW17: SW_Push; SW_Hotswap_Kailh_MX_1.00u
SW8, SW15: SW_Push; SW_Hotswap_Kailh_MX_2.00u_90deg
SW16: SW_Push; SW_Hotswap_Kailh_MX_2.00u
U1: RP2040; QFN-56-1EP_7x7mm_P0.4mm_EP3.2x3.2mm
U2: W25Q128JVS; SOIC-8_5.3x5.3mm_P1.27mm
U3: AMS1117-3.3; SOT-223-3_TabPin2
Y1: 12MHz; Crystal_SMD_2016-4Pin_2.0x1.6mm

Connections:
+5V: C6.1, J1.A4 (VBUS), J1.A9 (VBUS), J1.B4 (VBUS), J1.B9 (VBUS), J2.2, J4.1, J4.2, L1.3 (VDD), L2.3 (VDD), L3.3 (VDD), L4.3 (VDD), L5.3 (VDD), L6.3 (VDD), L7.3 (VDD), L8.3 (VDD), L9.3 (VDD), L10.3 (VDD), L11.3 (VDD), L12.3 (VDD), L13.3 (VDD), L14.3 (VDD), L15.3 (VDD), L16.3 (VDD), L17.3 (VDD), U3.3 (VI)
COL1: SW1.1, SW5.1, SW9.1, SW12.1, SW16.1, U1.11 (GPIO8)
COL2: SW2.1, SW6.1, SW10.1, SW13.1, U1.9 (GPIO7)
COL3: SW3.1, SW7.1, SW11.1, SW14.1, SW17.1, U1.8 (GPIO6)
COL4: SW4.1, SW8.1, SW15.1, U1.7 (GPIO5)
CS: R6.1, R7.2, U1.56 (~QSPI_SS), U2.1 (~CS)
D+: J1.A6 (D+), J1.B6 (D+), J4.4, R5.1
D-: J1.A7 (D-), J1.B7 (D-), J4.3, R4.1
DIN: L1.2 (DIN), U1.12 (GPIO9)
DOUT: L17.4 (DOUT)
GND: C1.2, C2.1, C3.1, C4.2, C5.1, C6.2, C7.2, E1.C, E1.MP, E1.S2, J1.A1 (GND), J1.A12 (GND), J1.B1 (GND), J1.B12 (GND), J1.SH (SHIELD), J2.1, J2.5, J2.MP, J3.2, J4.5, J4.6, L1.1 (VSS), L2.1 (VSS), L3.1 (VSS), L4.1 (VSS), L5.1 (VSS), L6.1 (VSS), L7.1 (VSS), L8.1 (VSS), L9.1 (VSS), L10.1 (VSS), L11.1 (VSS), L12.1 (VSS), L13.1 (VSS), L14.1 (VSS), L15.1 (VSS), L16.1 (VSS), L17.1 (VSS), P1.1, P2.2, R1.2, R2.2, U1.19 (TESTEN), U1.57 (GND), U2.4 (GND), U3.1 (GND), Y1.2 (G), Y1.3 (G)
MCU3.3V: C3.2, C7.1, R3.2, R7.1, U1.1 (IOVDD), U1.10 (IOVDD), U1.22 (IOVDD), U1.33 (IOVDD), U1.42 (IOVDD), U1.43 (ADC_AVDD), U1.44 (VREG_VIN), U1.48 (USB_VDD), U1.49 (IOVDD), U2.8 (VCC), U3.2 (VO)
unnamed: D1.2 (A), SW1.2
unnamed: D2.2 (A), SW2.2
unnamed: D3.2 (A), SW3.2
unnamed: D4.2 (A), SW4.2
unnamed: D5.2 (A), SW5.2
unnamed: D6.2 (A), SW6.2
unnamed: D7.2 (A), SW7.2
unnamed: D8.2 (A), SW8.2
unnamed: D9.2 (A), SW9.2
unnamed: D10.2 (A), SW10.2
unnamed: D11.2 (A), SW11.2
unnamed: D12.2 (A), SW12.2
unnamed: D13.2 (A), SW13.2
unnamed: D14.2 (A), SW14.2
unnamed: D15.2 (A), SW15.2
unnamed: D16.2 (A), SW16.2
unnamed: D17.2 (A), SW17.2
unnamed: J1.A5 (CC1), R1.1
unnamed: J1.B5 (CC2), R2.1
unnamed: L1.4 (DOUT), L2.2 (DIN)
unnamed: L2.4 (DOUT), L3.2 (DIN)
unnamed: L3.4 (DOUT), L4.2 (DIN)
unnamed: L4.4 (DOUT), L8.2 (DIN)
unnamed: L5.2 (DIN), L6.4 (DOUT)
unnamed: L5.4 (DOUT), L9.2 (DIN)
unnamed: L6.2 (DIN), L7.4 (DOUT)
unnamed: L7.2 (DIN), L8.4 (DOUT)
unnamed: L9.4 (DOUT), L10.2 (DIN)
unnamed: L10.4 (DOUT), L11.2 (DIN)
unnamed: L11.4 (DOUT), L15.2 (DIN)
unnamed: L12.2 (DIN), L13.4 (DOUT)
unnamed: L12.4 (DOUT), L16.2 (DIN)
unnamed: L13.2 (DIN), L14.4 (DOUT)
unnamed: L14.2 (DIN), L15.4 (DOUT)
unnamed: L16.4 (DOUT), L17.2 (DIN)
unnamed: P2.1, R6.2
unnamed: U1.52 (QSPI_SCLK), U2.6 (CLK)
unnamed: U1.53 (QSPI_SD0), U2.5 (DI/IO_{0})
unnamed: U1.55 (QSPI_SD1), U2.2 (DO/IO_{1})
unnamed: U1.54 (QSPI_SD2), U2.3 (~WP/IO_{2})
unnamed: U1.51 (QSPI_SD3), U2.7 (~HOLD/~RESET/IO_{3})
unnamed: P1.2, R3.1, U1.26 (RUN)
unnamed: R4.2, U1.46 (USB_DM)
unnamed: R5.2, U1.47 (USB_DP)
unnamed: C1.1, C2.2, U1.23 (DVDD), U1.45 (VREG_VOUT), U1.50 (DVDD)
unnamed: C4.1, U1.20 (XIN), Y1.1
unnamed: C5.2, U1.21 (XOUT), Y1.4
OUTA: E1.B, U1.3 (GPIO1)
OUTB: E1.A, U1.5 (GPIO3)
ROW1: D1.1 (K), D2.1 (K), D3.1 (K), D4.1 (K), U1.39 (GPIO27/ADC1)
ROW2: D5.1 (K), D6.1 (K), D7.1 (K), D8.1 (K), U1.38 (GPIO26/ADC0)
ROW3: D9.1 (K), D10.1 (K), D11.1 (K), U1.37 (GPIO25)
ROW4: D12.1 (K), D13.1 (K), D14.1 (K), D15.1 (K), U1.40 (GPIO28/ADC2)
ROW5: D16.1 (K), D17.1 (K), U1.41 (GPIO29/ADC3)
SCL: J2.4, U1.30 (GPIO19)
SCLK: J3.1, U1.24 (SWCLK)
SDA: J2.3, U1.29 (GPIO18)
SDIO: J3.3, U1.25 (SWDIO)
SW: E1.S1, U1.2 (GPIO0)

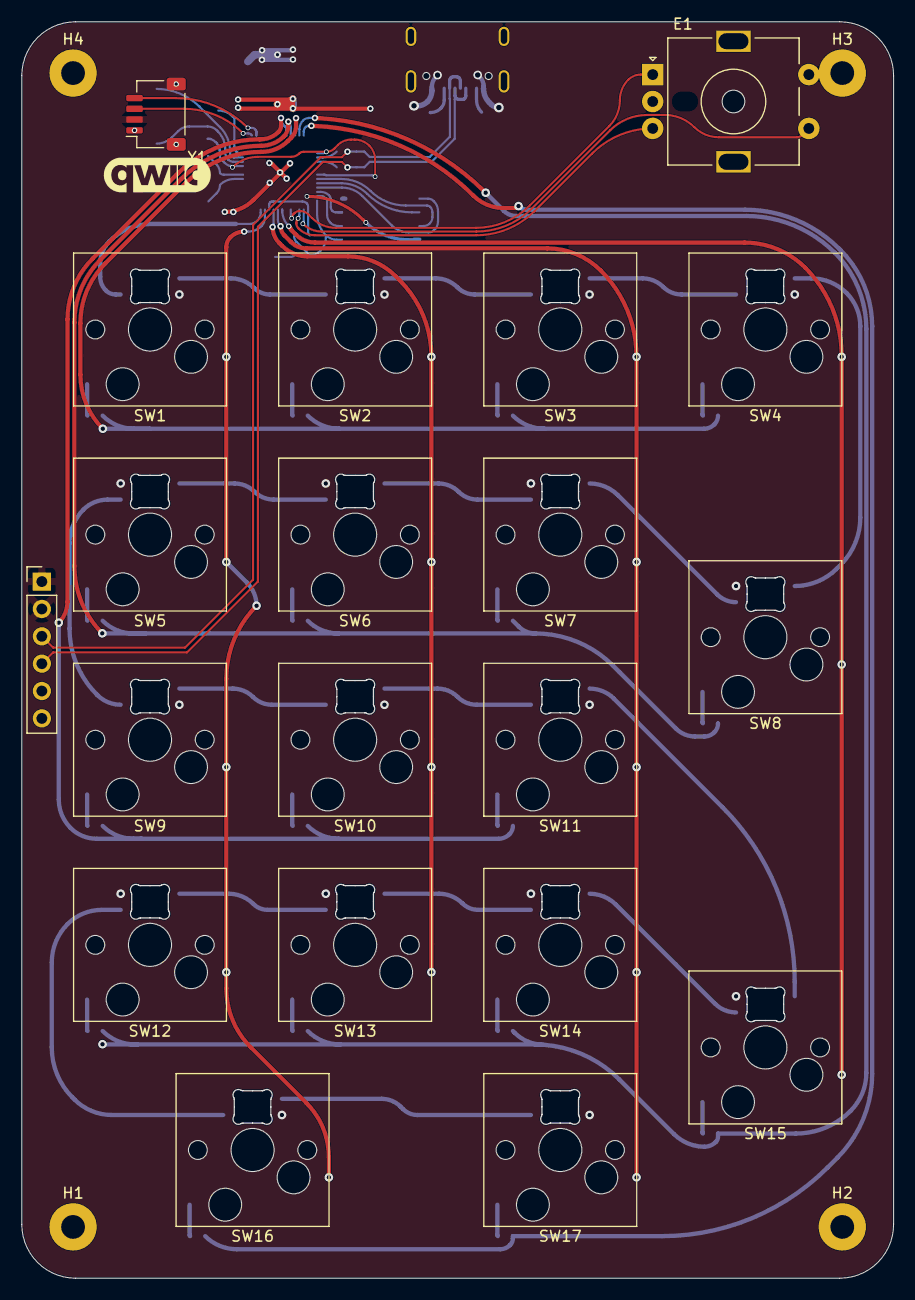
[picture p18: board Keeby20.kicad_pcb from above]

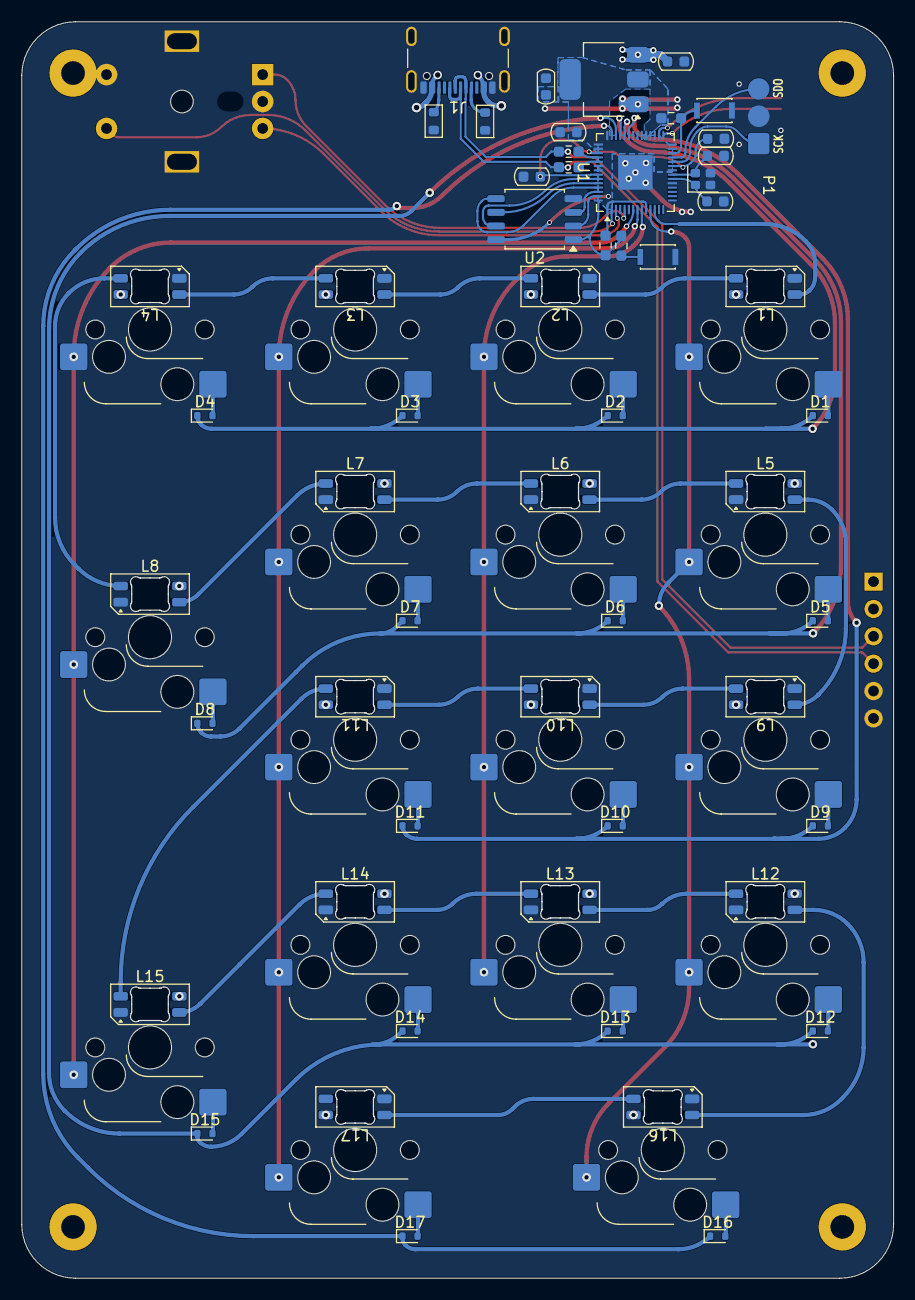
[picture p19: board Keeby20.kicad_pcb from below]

Board: 2 copper layers, 81.0 x 116.7 mm, 80 parts (56 on the bottom side), 70 nets.

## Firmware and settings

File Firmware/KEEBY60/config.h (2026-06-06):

#pragma once


#define I2C_DRIVER I2CD1
#define I2C1_SDA_PIN GP0
#define I2C1_SCL_PIN GP1

// OLED
#define OLED_DISPLAY_128X32
#define OLED_DRIVER_ENABLE

#define ENCODER_RESOLUTION 4
#define ENCODER_A_PINS {GP20}
#define ENCODER_B_PINS {GP21}

// Tapping time term || mod-tap keys (ms)
#define TAPPING_TERM 200

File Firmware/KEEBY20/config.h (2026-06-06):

#pragma once


#define I2C_DRIVER I2CD1
#define I2C1_SDA_PIN GP18
#define I2C1_SCL_PIN GP19

// OLED
#define OLED_DISPLAY_128X32
#define OLED_DRIVER_ENABLE

#define ENCODER_RESOLUTION 4
#define ENCODER_A_PINS {GP1}
#define ENCODER_B_PINS {GP3}

// Tapping time term || mod-tap keys (ms)
#define TAPPING_TERM 200

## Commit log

2026-06-06 Update README with device specifications
    Added specifications for total keys, knobs, display, PCB layers, and dimensions for both devices.
2026-06-07 Add Onshape full assembly link to README
2026-06-07 Update Onshape assembly link in README
2026-10-02 Update schematics in README.md
    Removed duplicate schematic image and added a new one.

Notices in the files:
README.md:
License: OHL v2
